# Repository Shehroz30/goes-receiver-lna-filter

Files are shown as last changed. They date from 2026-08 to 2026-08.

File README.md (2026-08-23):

# GOES Receiver

Made a GOES Receiver that operates on 1694.1 MHz, intended to interpret HRIT signals. This is the low noise amplifier and filter portion. 

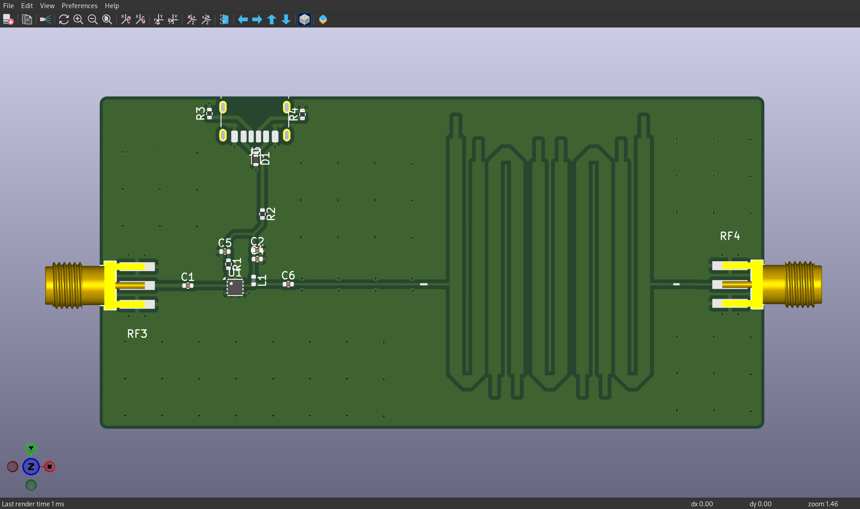
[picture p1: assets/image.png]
PCB Design

*PCB Render in KiCAD.*

## BOM:
- QLP9547 Low Noise Amplifier
- RF Coaxial Connectors
- USB-C Port
- Miscellaneous (resistors, inductors, etc)

## Filter Topology:
Designed using ADS, the filter is a 5th order Chebyshev filter based off of a hairpin design, intended to have 80 MHz bandwidth and operate as a bandpass filter. This compacts space and allows for the filter to fit on the PCB (which uses a PTFE Teflon dielectric). However, it does result in some insertion loss as can be seen in the attached graphs plotting S(1,1) and S(2, 1). At 1694.1 MHz, there's around -2.7 dB of insertion loss on S(2,1). Not bad!
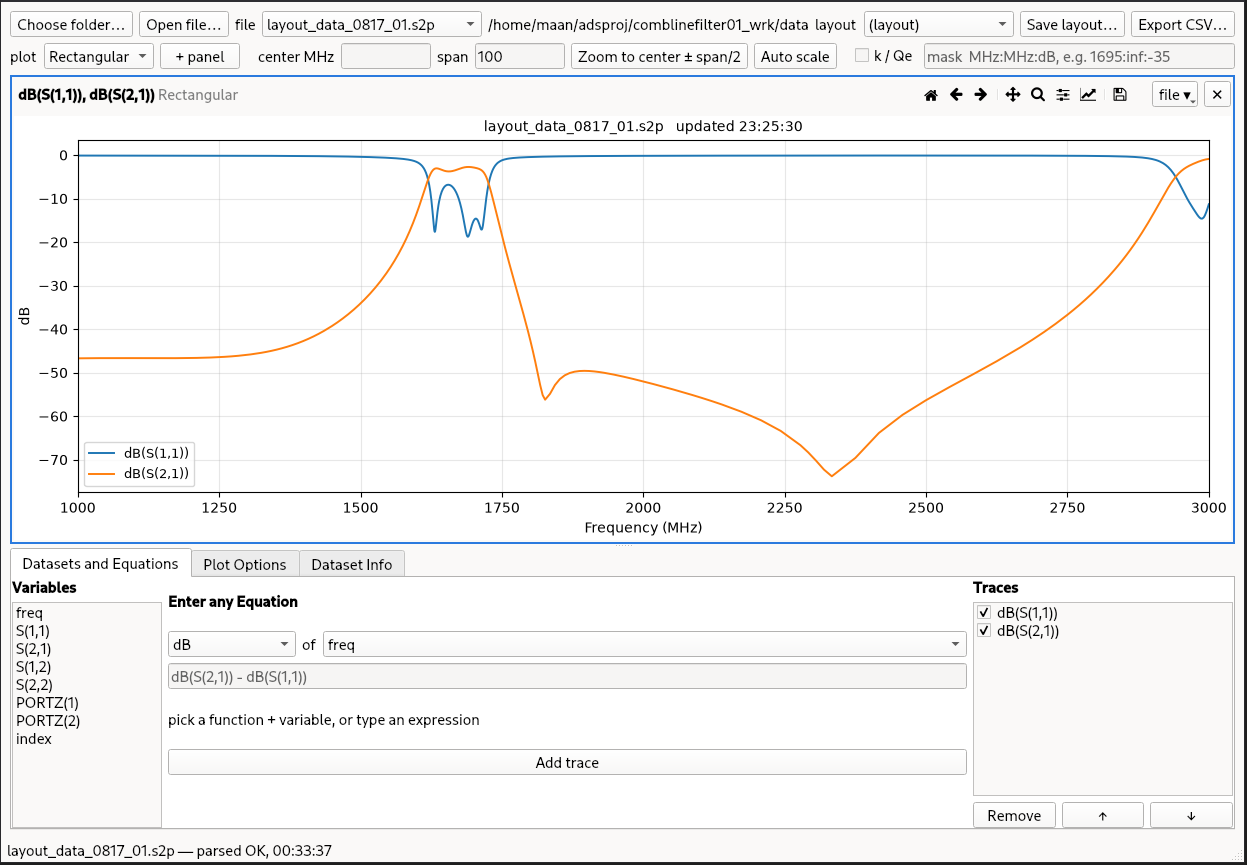
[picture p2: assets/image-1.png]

*Figure 1: Graph looking at the insertion loss of the filter.*

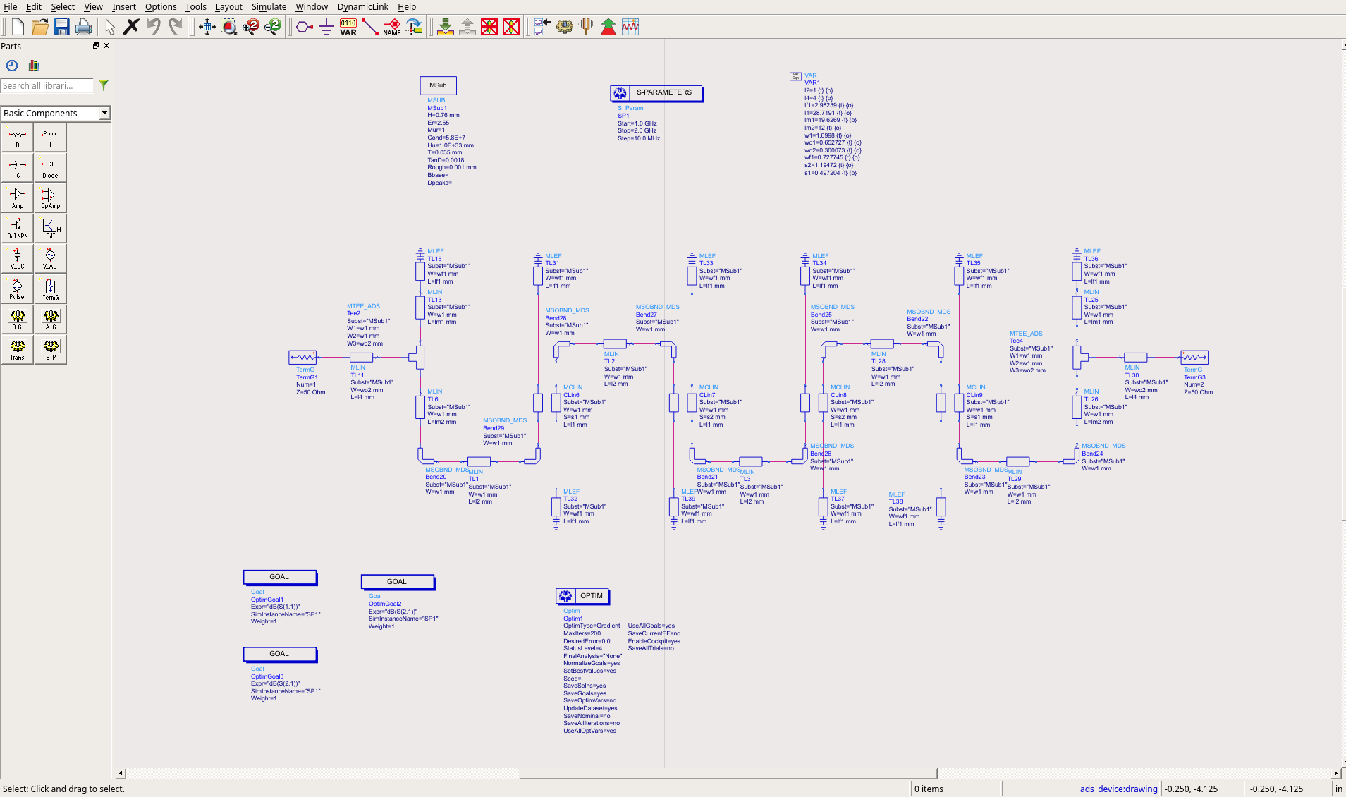
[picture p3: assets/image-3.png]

*Figure 2: Taken from ADS Studio, shows the schematic of the filter based off of microstrip lines.*

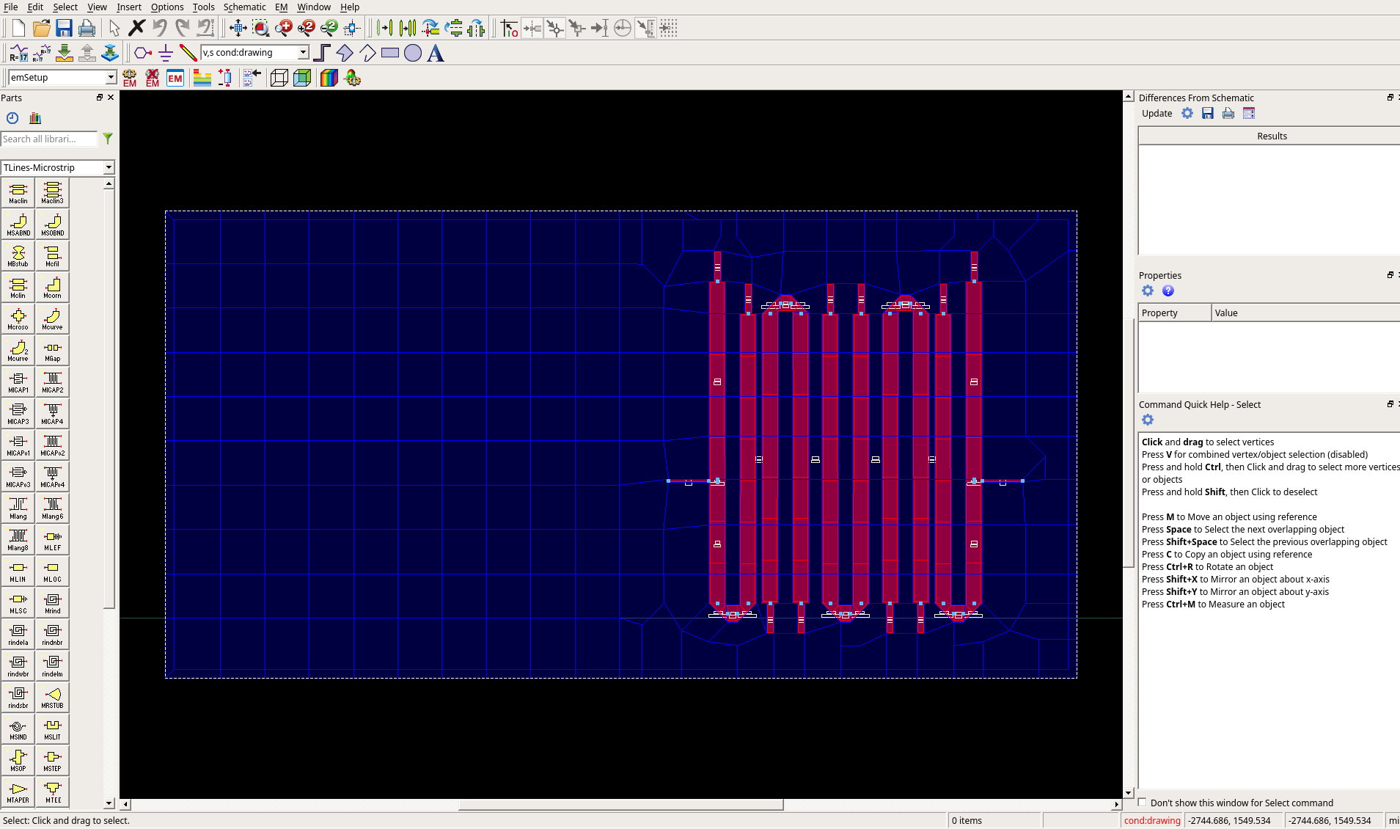
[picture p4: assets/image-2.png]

*Figure 3: Render of the Chebyshev filter on its own in KiCad.*

## What's left
Currently, software needs to be added and the board needs to be evaluated using a dish to receive the signals. 

## Gratitudes
Worked on with [@xuanmingl0415-arch](https://github.com/xuanmingl0415-arch)

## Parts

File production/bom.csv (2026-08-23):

Designator | Footprint | Quantity | Value | LCSC Part #
C1, C2, C5, C6 | 0402 | 4 | 100pF
C4 | 0402 | 1 | 1uF
D1 | D_SOD-523 | 1 | ESD5Zxx
FL1 | Untitled | 1 | KEV_KEV_GOES_Filter
J2 | USB_C_Receptacle_HRO_TYPE-C-31-M-17 | 1 | USB_C_Receptacle_PowerOnly_6P
L1 | 0402 | 1 | 18nH
R1 | 0402 | 1 | 76.9
R2 | 0402 | 1 | 0
R3, R4 | 0402 | 2 | 5.1k
RF3, RF4 | SMA-SMD_BWSMA-KE-P001 | 2 | BWSMA-KE-P001 | C496550
U1 | DFN-8-1EP_2x2mm_P0.5mm_EP1.05x1.75mm | 1 | QPL9547 | C5367093

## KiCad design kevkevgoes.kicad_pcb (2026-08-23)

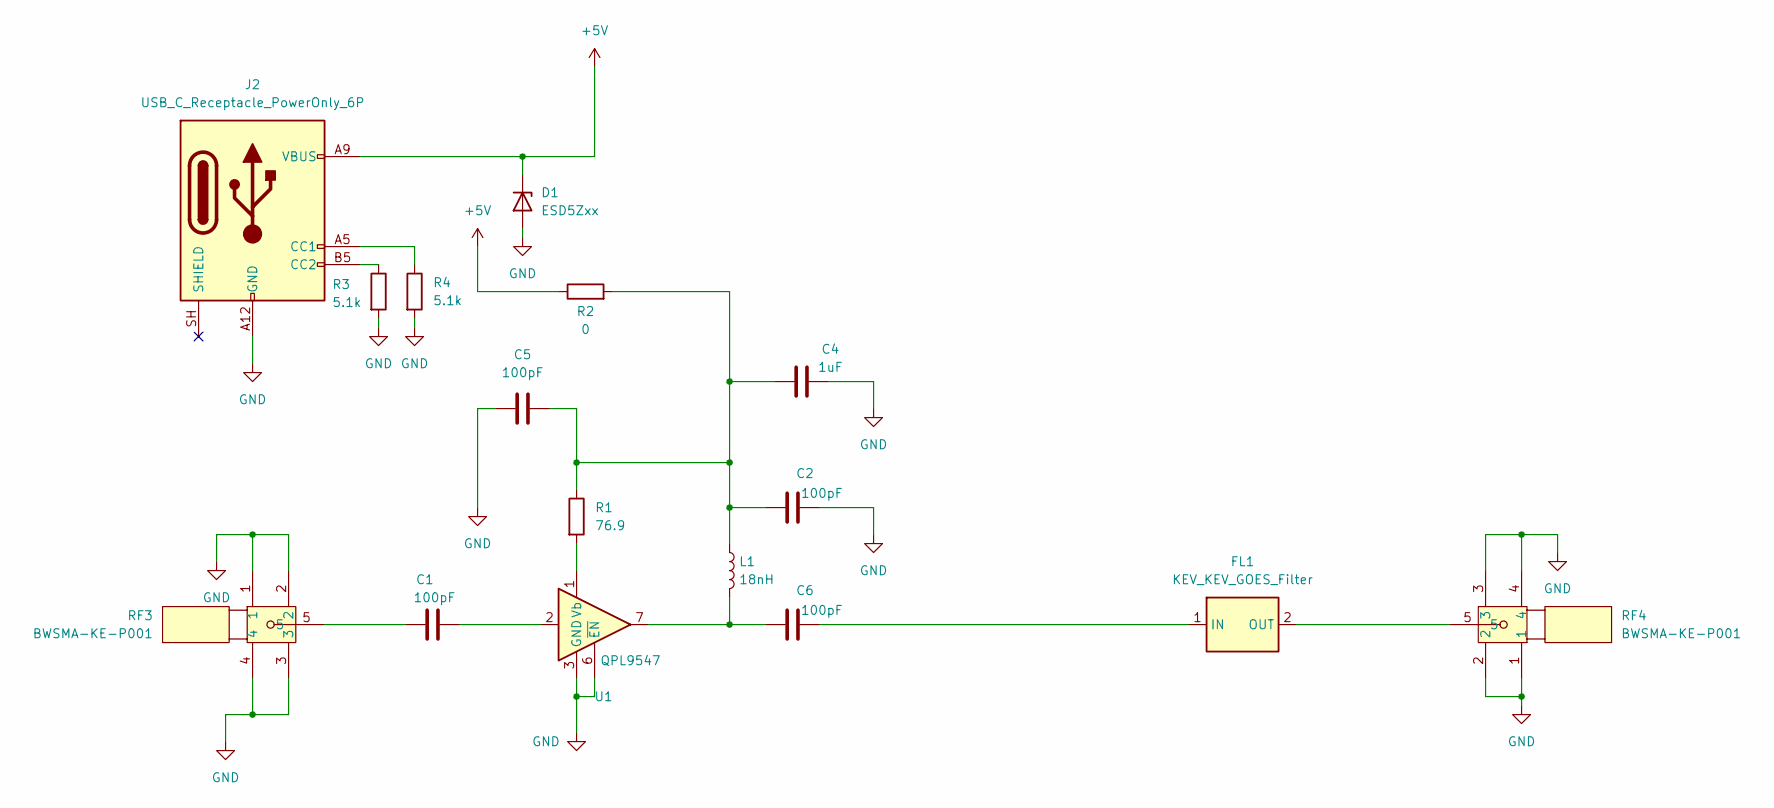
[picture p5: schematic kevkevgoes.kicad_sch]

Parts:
C1, C2, C5, C6: 100pF; C_0402_1005Metric
C4: 1uF; C_0402_1005Metric
D1: ESD5Zxx; D_SOD-523
FL1: KEV_KEV_GOES_Filter; Untitled
J2: USB_C_Receptacle_PowerOnly_6P; USB_C_Receptacle_HRO_TYPE-C-31-M-17
L1: 18nH; L_0402_1005Metric
R1: 76.9; R_0402_1005Metric
R2: 0; R_0402_1005Metric
R3, R4: 5.1k; R_0402_1005Metric
RF3, RF4: BWSMA-KE-P001; SMA-SMD_BWSMA-KE-P001; MPN BWSMA-KE-P001; LCSC Part C496550
U1: QPL9547; DFN-8-1EP_2x2mm_P0.5mm_EP1.05x1.75mm; LCSC C5367093

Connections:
+5V: D1.1 (K), J2.A9 (VBUS), J2.B9 (VBUS), R2.1
GND: C2.2, C4.2, C5.1, D1.2 (A), J2.A12 (GND), J2.B12 (GND), R3.2, R4.2, RF3.1, RF3.2, RF3.3, RF3.4, RF4.1, RF4.2, RF4.3, RF4.4, U1.3 (GND), U1.4 (GND), U1.5 (GND), U1.6 (~EN), U1.8 (GND), U1.9 (GND)
unnamed: C1.1, RF3.5
unnamed: C1.2, U1.2
unnamed: C2.1, C4.1, C5.2, L1.1, R1.1, R2.2
unnamed: C6.1, L1.2, U1.7
unnamed: C6.2, FL1.1 (IN)
unnamed: FL1.2 (OUT), RF4.5
unnamed: J2.A5 (CC1), R4.1
unnamed: J2.B5 (CC2), R3.1
unnamed: R1.2, U1.1 (Vb)

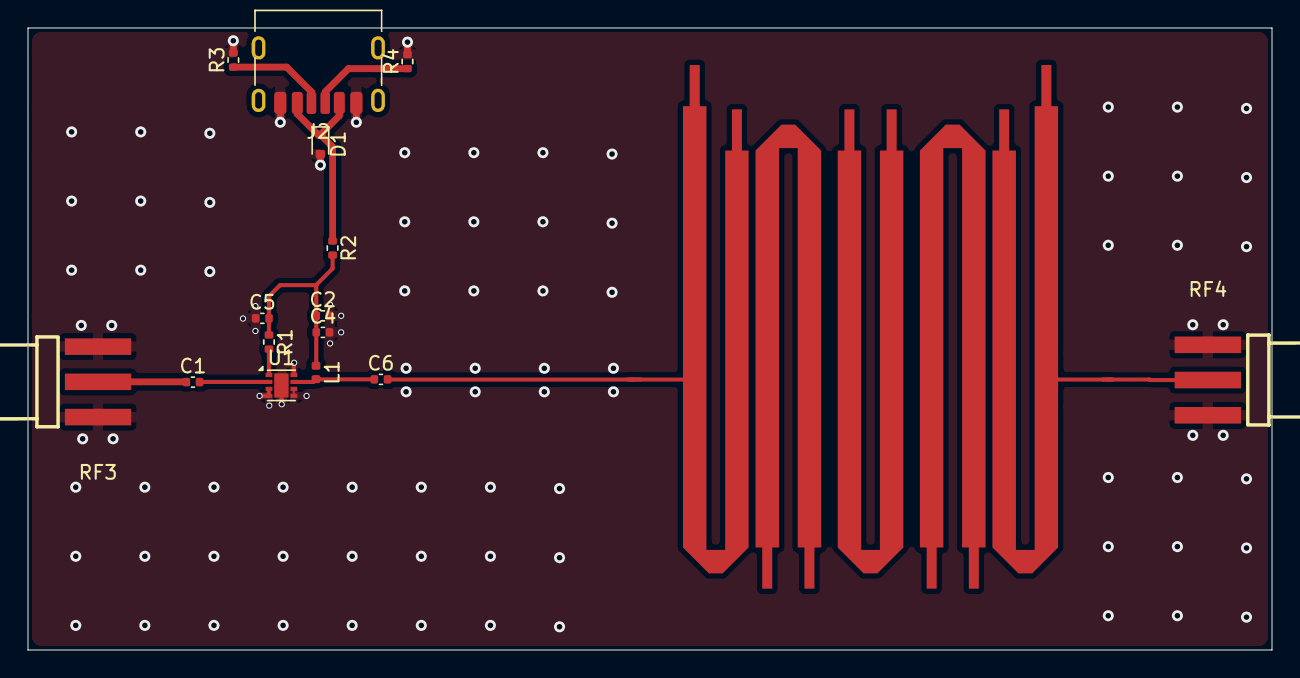
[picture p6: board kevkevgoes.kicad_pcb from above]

Board: 2 copper layers, 90.0 x 45.0 mm, 16 parts (0 on the bottom side), 11 nets.
